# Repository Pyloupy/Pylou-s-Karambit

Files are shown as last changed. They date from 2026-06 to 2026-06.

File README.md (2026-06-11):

# Pylou-s-Karambit








Hey there ! This is the GitHub Repo where I'll show my creation based of the Reaver Karambit from Valorant (cf photo down below) that I wanted to bring to life!

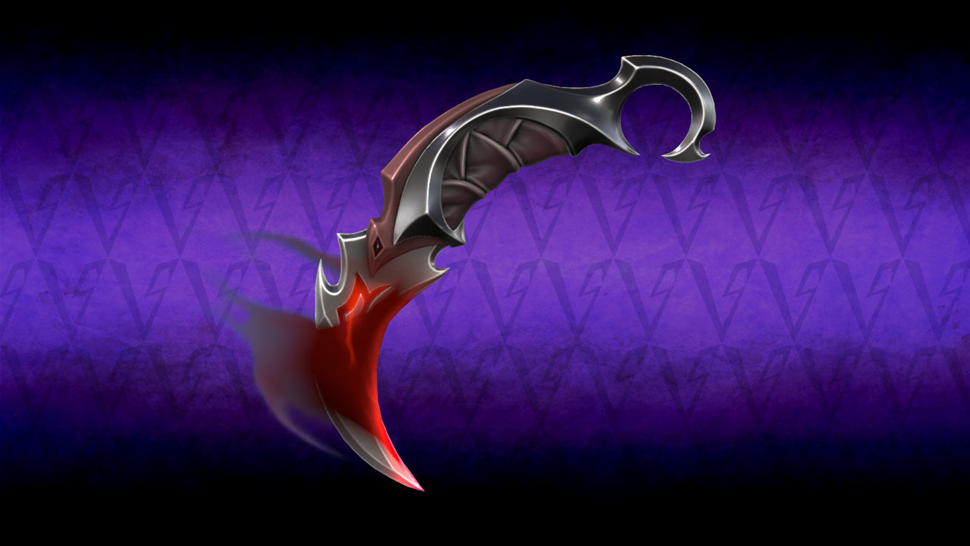
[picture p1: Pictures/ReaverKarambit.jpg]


I tried to make it as realistic as possible with LEDs A smoke generator and even movement and voice recognition!  You should see everything here that will make you able to recreate my work, GL :)
# Why ?
Well, you should first know that my work is completly useless and is purely aesthetic. It'll be able to cut butter at his peak or maybe set my house in fire if I did my job wrong ;-;

I wanted to make it as a fan of the game Valorant. A lot of recreation has been made because it is a very popular weapon skin in the game, but none tried to push the reality to the maximum, thats why I'm here !

At first, I created a prototype with not a lot of brain work behind it and it didnt work at all (as you can see in the photo) and I didn't even know why, so I gave up.

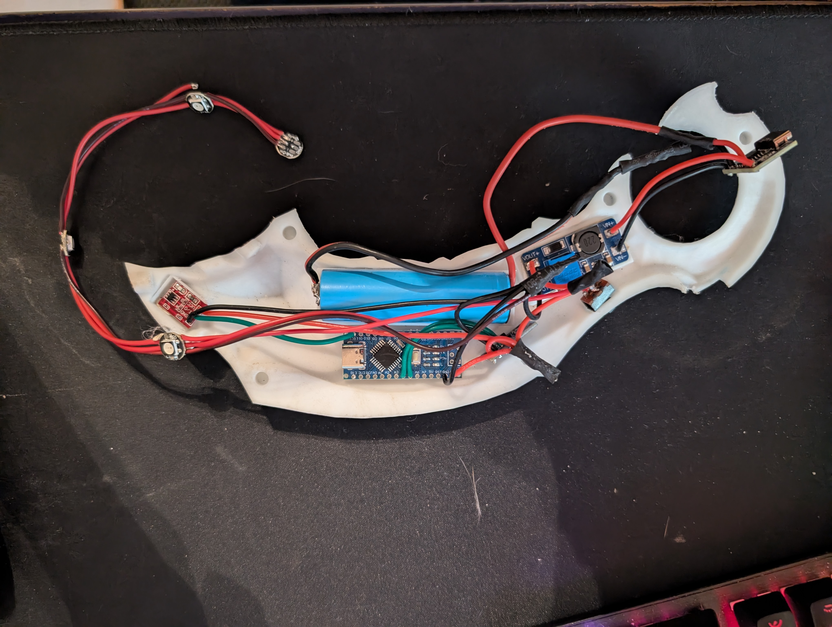
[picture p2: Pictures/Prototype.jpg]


My friends made a little fun of me and that's why when I hear of the Fallout project I decided to take my revenge and make a clean work that will work! That's enough story telling, let's get in the details !
# Functionalities
Here's an exhaustive list of the functionnalities I implemented into my Karambit that maybe I'll extend later when completing the build!
- A rechargeable Smoke generator based on a E-cig
- RGB Show! With the help of an SK6812MINI and an acrylic tube to make special effects!
- Movement detection : A list of pre-trained movement to make different effects base on which movement you execute! 
- Edge AI Speech recogntion : A list of pre-trained word-orders to activate/desactivate certain functionalities using a custom-trained TinyML model via the PDM microphone
- Magnetic sensor : to detect if it is on his stand (more and that down below)
- Ultra-Low Power Management : Hardware-level Deep Sleep (SYSTEM OFF) implementation with QSPI flash memory shutdown and Wake-on-Motion via I2C intterupts, to save battery life.
- Hardware Fail-Safe: Native Watchdog Timer (WDT) implementation directly addressing the ARM Cortex-M4 to prevent software failure / thermal runaway

I really wanted to make this as complete as possible while keeping it the size of a real karambit that can fit in you hands, it was quite a challenge.
# Zine page
But an image is worth thousands of words! I made the CAD of my model in blender because the karambit is a really complex shape and I'm a lot more comfortable with blender even thought it's not really made for this job and I had to deal with some issues due to blender. 

But I made a little render with an exploded view effect and I think it turned out well:

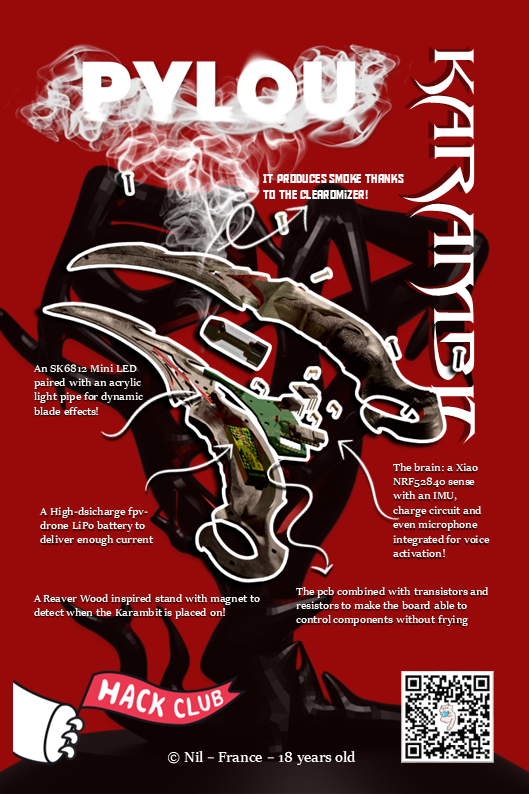
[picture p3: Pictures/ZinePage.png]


The design is around the exploded view where you can see every components linked to the explanation of his role. I think it's a cool way to show off everything you have to fit in this tiny space to make it work!
For the text name, I tried to make an effect with the smoke comming out of the resistor, although I think the idea is great, I'm not completly happy with the effect it gives. But overall I'm happy with my zine page!  
If you want, In the CAD folder you can find the "render.blend" file where I worked on the exploded view if you want to play with it :)

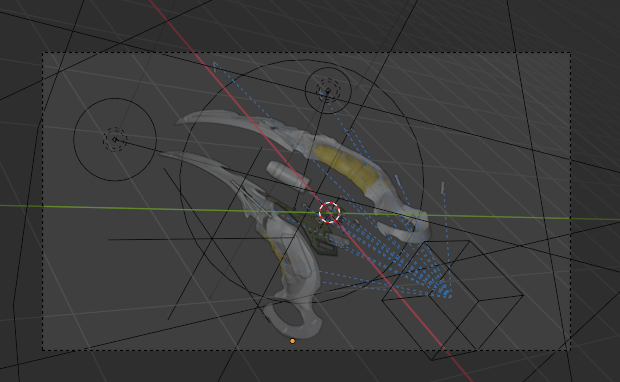
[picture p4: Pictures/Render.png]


# CAD
### the Karambit
Talking about CAD, as I said I did almost everything in Blender to work around the complex shape that the karambit is:

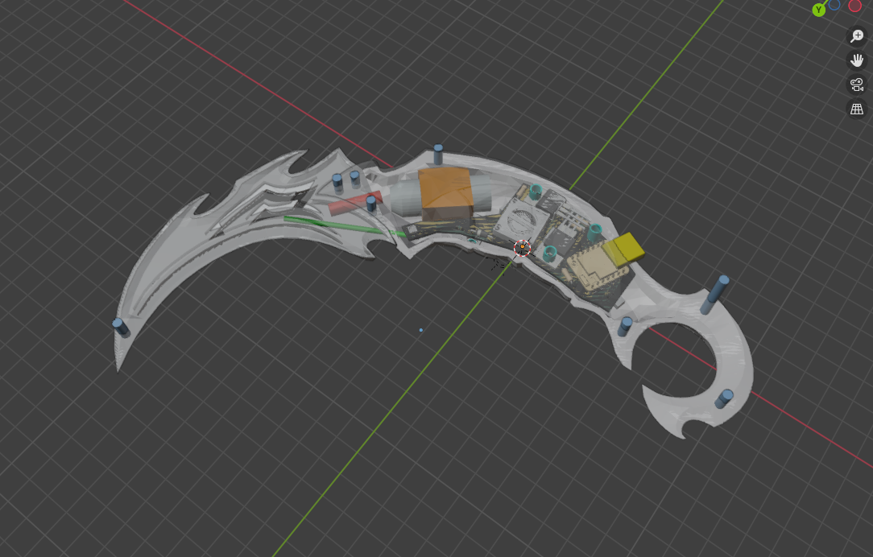
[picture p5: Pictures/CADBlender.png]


But I did use SOLIDWORKS when I had to model i couldn't find on the internet or to make a special adapter and then imported it in Blender.   
I think it is really more easy to work with it for placing components the way you want, and since I had so little space to work with it was perfect for me.  
I had to think about a way to:
- insert the pcb inside the handle
- fit the resistor inside the handle close the blade side and a good way to fix it
- make each part (2 handle part, 2 blade side) fit together with screw for a strong grip since you have to spin the karambit
- make a way to conduct light to the blade with no LEDs inside of it because the pcb couldn't go into the blade
- place usb-c port, reed sensor and cork hole for the tank in a way that is comfortable and make sense with the way it is held in the stand
Everything have his place and it's really not made randomely, I, in fact, made the pcb in the same time as the CAD files to rearange everything as I wanted to for optimal placement
### Stand
In the first place I wanted only to build the Karambit, but when I worked on the firmware, I realised that the board I selected didn't have a way to wake up itself throught the IMU.  
That's why I wanted a backup option for the wakeup system and I thought about a magnetic option with a stand. The idea is that when the karambit detects a magnet placed in the stand, It goes to sleep to save the battery, and when take it off it wakes up with special effects!

I wanted a dark and stylized way to show off the reaver karambit. With a bit of research I found this picture reference of the reaver woods from the game wayfinder that i didnt't even know existed:

<image src=./Pictures/ReaverWoods.png width=400>
  
I thought it completly matched the theme and made a model based on this reference image. It holds the knife with different branches and goes around like a protection.

<image src=./Pictures/Stand.png width=600>
  
I made it really big and I will have to print it in 5 different parts and glue it together, I really hope it will be strong enough to hold everything, but it should do the job.
### Adapters 

I also made some adapter in SOLIDWORKS to:
- Fix the resistor inside the handle
- Fix the pvc tube to the resistor
- Convert the airflow from the fan to the inside holes of the resistor

Thats is pretty much all for the CAD design

# PCB
Now for the PCB part! I did everything in Kicad which is a free software you can find [here](https://www.kicad.org/download/)
### Schematic
Overall, the schematic and electrical design is not really complicated as it consist only of the xiao nrf52840, pins for the battery, pins for the resistor, pins for the fan, 2 IRLZ44N mosfets and a couples of resistors and diode for protection.  
Here's the schematic:

<image src=./Pictures/Schematics.png width=800>
  
As you can see the mosfets control both the fan and resistor as the current could kill the microcontroller if connected directly to it.  
There are 10k pull-down resistors linked to the mosfets to prevent any unwanted turn on when the board is in deep sleep. The schottky 1N5819 diode is connected to the fan to prevent any back current that could fry the xiao board.

That is pretty much it, as I said nothing really complicated for the schematic, the hard part was to fit everything -->
### PCB design
Since the xiao boards include the charging system, IMU and microphone on itself, it really made the job easier.  
But the pcb itself is a bit small and in a strange shape since it had to fit in the curved form karambit.  
I think I couldn't really more include more components with the way I shaped the pcb, with the large trace I had to place for the current to flow easily into the heat resistor.
Here's how it looks:

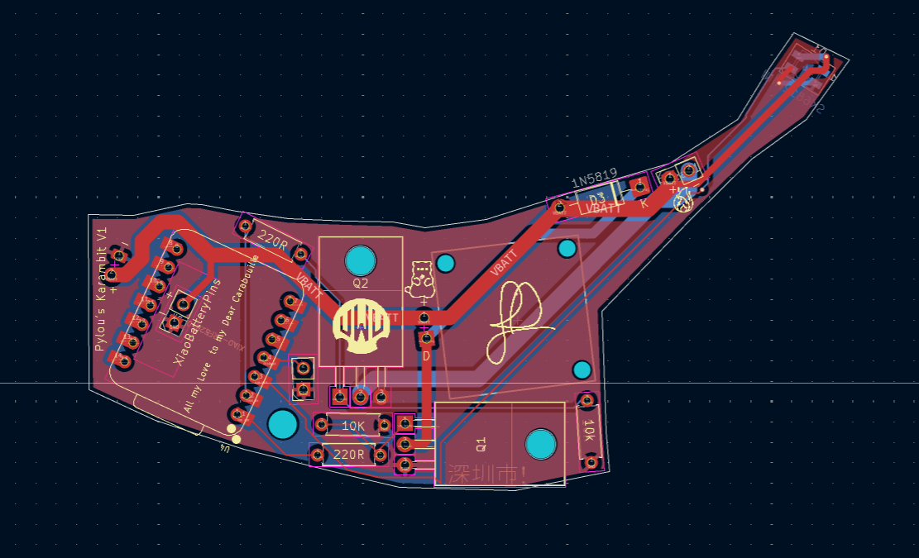
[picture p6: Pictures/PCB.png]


I also added holes to scew the pcb to the handle of the karambit, and I used the mosfets holes to fix the battery beneath the pcb.  
The SK6812MINI LEDs is place as far away as I could to place it near the blade of the karambit, that is why the pcb has this strange L shape.  
You could see that there is two times pins for the battery. The first one on the left side is to connect it to the BT2.0 connector that my battery use for a proper connection. The second one inside the xiao nrf52 footprint is placed this way because the pins for the battery module inside the xiao board is beneath it, so it will be easier for the solder job to place it this way instead of directly connect it to the BT2.0 connector.  

I have to mention I choosed to use the DIP version of the board and not the SMD one because I'm still a beginner with soldering electronics and it is way more easier to do it this way. But a way of impromevement could be to use the SMD version to not have two little wires hanging between the pcb and the microcontroller.

I think there is some details I could improve on the pcb but I didn't want to make it to complex for a V1 of this project as I really want to make it work like a charm !
# Firmware
## Installation
### Arduino
You will have to get the [Arduino IDE](https://support.arduino.cc/hc/en-us/articles/360019833020-Download-and-install-Arduino-IDE) to flash the xiao board. Then you will have to install the Seeed Xiao board inside the Arduino IDE (tutorial [here](https://wiki.seeedstudio.com/XIAO_BLE/#getting-started)) and make sure you select the mbed boards and not the classic one!  
After that you will have to install a couples of arduino libraries that I worked with, I made a folder called "Librairies" that you can copy-paste into your local Arduino folder in what I believe is ```/username/Documents/Arduino/librairies``` / install zip libraries or simply get your own with the library manager inside arduino. There is a txt file with links to all of them.

Then you'll just have to open the ReaverFirmware.ino file select the xiao nrf52840 board (mbed version) and flash the firmware, this can take a while with the speech recognition compilation.
### Custom Speech Recognition
I already trained a model with my voice, but I'm not sure it'll respond to yours. That's why I made a tool to make your own dataset and train your own speech recognition model! First you'll have to flash the ```AudioRecordPC.ino```file to the xiao board.   
Then there is a python script to record directly from the xiao nrf52 microphone! You will have to install [python](https://www.python.org/downloads/) and the keyboard librarie first with this simple command: ```py -m pip install keyboard``` .  
Then modify in the script the name of your folder you want to get the dataset in, and the name of the first order you are recording. Record you first word press "r" and repeat. The more you do the better, I'll say minimum of 100 of them. Then press "q" to quit and save every file. 

Now you just have to follow this [tutorial](https://wiki.seeedstudio.com/XIAO-BLE-PDM-EI/) with you own dataset. Here's the parameters that I personnaly used and that is working great for me: <image src=>
Don't forget to change in the Firmware code the import of the library to your own !  
⚠️ I recommend you record you files after build (see below) to have more realistic conditions
### Movement Recognition
For this, we again will use Edge Impulse AI, basically just follow the steps of [this](https://wiki.seeedstudio.com/XIAOEI/) tutorial and create your own movements you want to recognize.
It is basically the same thing as the voice recognition but here, you can easely record your samples via the website and nodejs, that will have to install (but everything is shown on the tutorial)

In the Firmware Tools folder you will find a script that makes you able to test your model. It is just adapted from an exemple of the movement recogntion library. It is basically the same thing but without installing additional library and using the official Seeed Xiao Nrf52 LSM6DS3 library.

Again the compilation can take a while, be patient.

It is very basic, and I will work on a continuous version to make it smooth and non-blocking. (This is also true for voice recogntion, but in this case the model also needs to be optimized)

(PS: implementation in the main code hasn't been made yet, it'll be when I'll start building)

If you don't want complex movement recognition you could just use this bit of code to detect any type of fast movements with acceleration:
```cpp
//in the void loop:
  currentMillis = millis();
  float gX = myIMU.readFloatAccelX();
  float gY = myIMU.readFloatAccelY();
  float gZ = myIMU.readFloatAccelZ();

  float magnitude = sqrt(gX * gX + gY * gY + gZ * gZ);
  /* Serial.println(gX);
  Serial.println(gY);
  Serial.println(gZ); */
  // Detect rapid movement
  if (magnitude > 2.5) {
    Serial.println("slash detected");
    fumee(); //Function for effetcs/smoke
    //delay(1000);
    startMillis = millis();//restart timer coz movement detected
  }else{
    fumeeOff(); //Function to disable effects/smoke
  }
```
(It's the code written in the main loop Firmware for now)
## How does it work ?
For this part, I really wanted to do an advanced job and use all the potential that the xiao nrf52840 as to offer.  
I choosed to use Arduino code for this project as it is efficient and well more documented than the other programming language options.  

There is a couple of files that is in the firmware folder, and I tried to comment everything on the way they work if you want to take a closer look!
Most of these folders are the firmware divided in multiples part to test every functionality of the firmware separetely:
- Testing the Deep Sleep mode and the different way to wake it up (IMU or reed sensor)
- Testing the Voice recognition model and the different way to use it (Continuous or no)
- Testing the watchdog (natively implemented inside the nrf52 chip from Nordic Semiconductor, this was a bit complicated to make it work) to prevent any errors crashing with the voice AI model
- Battery reading test
- IMU testing
- Fan/Led/mosfets testing
These scripts could help you when building the Karambit to check every components and maybe find what isn't working (if it's not working) especially with voice and movement recognition and maybe calibrate the battery reading, Deep Sleep and watchdog should work perfectly.

Have fun creating new effects/movement/orders to you karambit to make it personal!
#BOM
Now here's the BOM or aka how to get your components.  
There is link for everything mainly using Aliexpress. I personaly took the resistor with a French reseller so maybe you'll have to look somewhere else, (just search the model name).  
For paint, I took mine in a local store, be free to pick any colour you want to make your favorite variant of the reaver karambit!  
I ordered my pcb on Jlcpcb, it is great and cheap. For filament I used what I already had, but take whatever you want, it's best if it is strong and heat resistant.  
Careful for prices they may vary over time, Aliexpress is very volatile with there prices

Here's the BOM (you can also find it in CSV and xlsx format in the files):
| Item | Specs | Quantity | Buying Price(€) | Unit Price| Total Price (€) | Link | Tips |
| ---- | ----- | --- | --- | --- | --- | ---- | ---- |
| 18x14mm fan | 0.2 cfm, blow the smoke as it is in a closed case | 1 | 4.29 | 4.29 | 4.29 | [Link](https://fr.aliexpress.com/item/1005010476941631.html) | |
| 1N5819 Diode | Reverse polarity protection for the fan | 1 | 1.33 | 0.0248 | 0.0248 | [Link](https://fr.aliexpress.com/item/1005001552094086.html) | Others diodes will work, check the specs and measurement | 
| 100x2mm acrylic tube | Conduct the light into the blade | 1 | 1.8 | 0.171 | 0.171 | [Link](https://fr.aliexpress.com/item/1005005536829247.html) |  |
| M2xL2xOD3.2 insert | to fix the blade the the handle | 5 | 1.9 | 0.019 | 0.095 | [Link](https://fr.aliexpress.com/item/1005006472702418.html) | It'll be cheaper to just buy a kit of different type of inserts |
| M2xL4xOD3,2 insert | to fix the 2 parts of the knife together | 6 | 2.25 | 0.0225 | 0.135 | [Link](https://fr.aliexpress.com/item/1005006472702418.html) |  |
| M3xL5xOD4,2 insert | to fix the pcb via the transistors holes | 3 | 1.82 | 0.0364 | 0.1092 | [Link](https://fr.aliexpress.com/item/1005006472702418.html) |  |
| Battery BETAFPV LAVA II 1S 480mah | LiHv with 95C rating to ensure enough current | 1 | 15.29 | 3.54 | 3.54 | [Link](https://fr.aliexpress.com/item/1005010775720329.html) | Other batteries could work just be sure the C rating is high enough (hard to check on most Aliexpress battery where only fpv drones C rating are precised) |
| Reed switch NC  | Low voltage GPS-23 (act as a sensor to detect if it's in the stand) | 1 | 5.79 | 5.79 | 5.79 | [Link](https://fr.aliexpress.com/item/1005006926125113.html) |  |
| Seeed Studio Xiao nRF52840 Sense | 64 Mhz processor, IMU and microphone integrated | 1 | 18.19 | 18.19 | 18.19 | [Link](https://fr.aliexpress.com/item/1005006988944671.html) |  |
| BT 2.0 male cable | to cleanly connect the battery to the pcb | 1 | 3.59 | 1.945 | 1.945 | [Link](https://fr.aliexpress.com/item/1005009623841974.html) |  |
| SK6812MINI LED | 35 35 ARGB Led  | 1 | 10.89 | 0.1089 | 0.1089 | [Link](https://fr.aliexpress.com/item/1005004931260882.html) | You should modify the pcb and take SK6812MINI-E (the E is important) It's a lot more easier to solder, I already have those so i will use them (in pain) |
| GS Air Eleaf Clearomizer | 2.5 ml tank / 1,5 ohm coil (included) | 1 | 7.5 | 7.5 | 7.5 | [Link](https://www.oliquide.com/Clearomiseurs-Eleaf-Eleaf-GS-Air.) |  |
| Transistor IRLZ44N | 47A max, Vgs=2V, to control both fan and heat coil | 2 | 2.06 | 0.206 | 0.412 | [Link](https://fr.aliexpress.com/item/1005009876208141.html) | Should be overkill, I took them coz I already had them |
| 6mm diameter PVC Tube | 6mm exterior diameter 4mm interior diameter, to conduct the smoke to the blade | 1 | 2.09 | 2.09 | 2.09 | [Link](https://fr.aliexpress.com/item/1005006173546510.html) |  |
| M2 Screws | Screws different lengths kit | 1 | 5.09 | 5.09 | 5.09 | [Link](https://fr.aliexpress.com/item/1005007278965396.html) | Might have to cut them, make sure to put a bolt before to not break the thread |
| Magnet | 8mm diameter | 1 | 3.59 | 0.07 | 0.07 | [Link](https://fr.aliexpress.com/item/1005011969218794.html) |  |
| Anti-slip pads | for the stand | 7 | 1.8 | 0.018 | 0.12 | [Link](https://fr.aliexpress.com/item/1005008980666002.html) |  |
| 200/1K Ω resistors | for transistor signal and pull-down | 2 each |  |  |  | Take any kit of resistors on Aliexpress it'll be useful in the future |  |
| Hyper CF PLA Filament | For printing the handles, blades, stand and adaptaters | 1 | 34.99 | 34.99 | 34.99 | [Link](https://store.creality.com/fr/products/hyper-pla-cf-carbone-fibre-1-75mm-filament-dimpression-3d-1kg) | It's just what I will be using coz i have it in stock, but anything can do the job ABS will be better for heat coil |
| Fake Leather | Auto-adhesive layer | 1 | 4.99 | 4.99 | 4.99 | [Link](https://fr.aliexpress.com/item/1005008381916334.html) |  |
| Mettalic Paint | Shiny paint weeee | 1 | 5 | 5 | 5 | Bought from local store |  |
| Red Metallic Paint | Shiny paint weeee | 1 | 5 | 5 | 5 | Bought from local store |  |
| PCB | 1.6mm two layers | 1 | 3 | 0.6 | 0.6 | Got it from jlcpcb but use whats cheaper in your region (jlcpcb is a great choice tho) |  |
| Shipping Price |  | ~10-15€ |  |  |  |  |  |
| Total Price |  | 109.55€ | 128.88$ |  |  |  |  |
| Total Buying Price (Because you'll buying multiples at once) |  | 150.45€ | 177$  |  |  |  |  |

# Build time !
It's now time to make the Karambit! If you're confused any time, be free to check the blender file to understand where everything is placed! Everything is named and (more or less) organized, I hope you'll understand everything :)

### **Step 1:** Printing

First print everything from the STLs folder with your filament, it should be around 800g gram worth of filament, (I hope for you that everything fits in your printer, for reference mine is an ender 3 V3 KE).  

⚠️ Be careful when printing the stand, you will have to stop the print at a certain height to insert the magnet inside the branches and then resume print.
Then glue everything together for the stand, sand it and paint it if you think that is necessary. I recommend you to do it at least for the Karambit parts to make it cleaner!
Don't forget to place the anti-slip pads below the stand for a stable structure!
Place the fake leather into both handles, mines auto-adhesive if you take the one linked in the BOM

### **Step 2** soldering:

Beforehand be careful with the reed sensor, you will have to cut a platic part from it : 

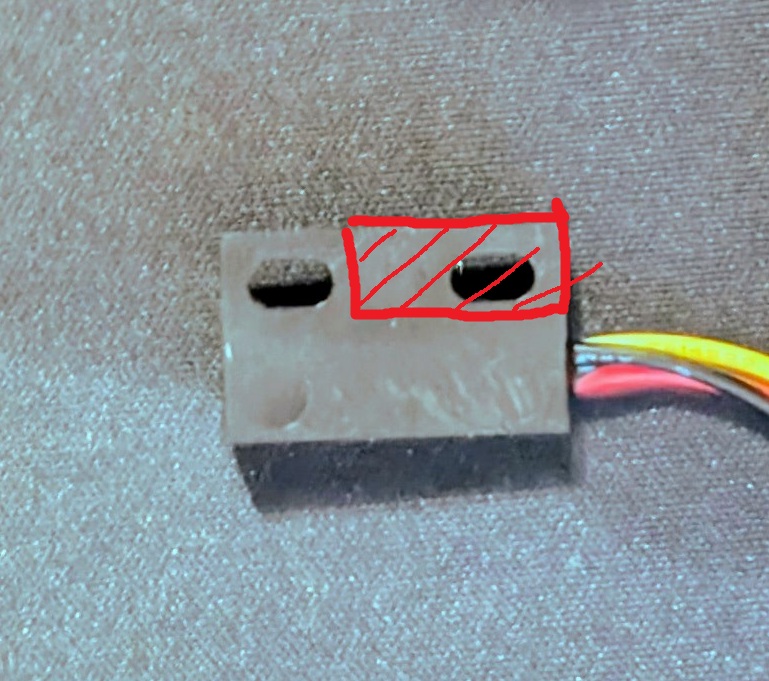
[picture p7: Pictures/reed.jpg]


without that it won't fit.  
Solder the xiao nrf52840 (dont forget connection for the battery), 200/1k ohms resistor, both mosfets, battery cable, fan, Schottky diode, SK6812MINI Led and Reed switch (let enough cable to play with) into the PCB and test everything with the different scripts in the Firmware folder.  

With a soldering Iron place the differents inserts in there places.  

Drill a 6mm hole into the Resistor's tank (check alignement with the hole made in the blade) and glue the tube to the tank with a waterproof glue like epoxy (will add a picture on that when i'll do it)
Solder + and - 18awg or less cable to the resistor as it shows on this image(then solder it to the PCB with enough length to play with):  (will add a picture on that when i'll do it)

### Step 3: assembling:
Fix the battery below the PCB with the adpater and screws/bolt.  
Fix the PCB into the handle with the scews.  
Fix the Resistor with the adapter printed and screws. (Careful for the orientation !) (PS: photo's comming when ill finish build)
Fix the Fan Adapter to the fan when screwing the fan.

Take the joint from the part you removed earlier from the clearomizer and place it on the adapter, then put it with the 6mm tube into the resistor. 

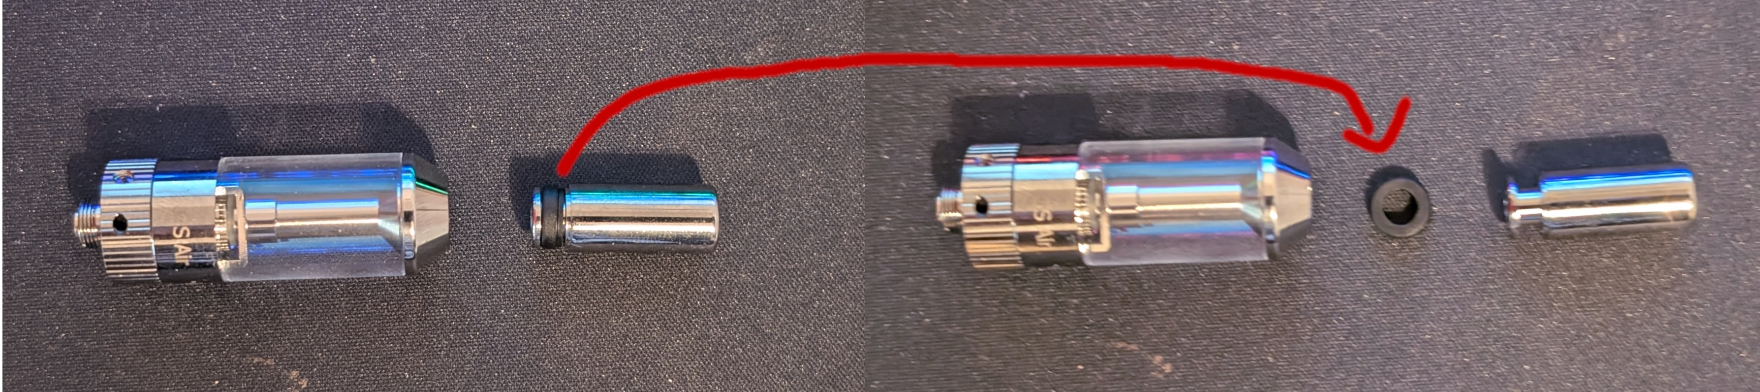
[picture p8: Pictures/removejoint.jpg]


Then block the left side of the base to force the airflow to go throught the coil : 

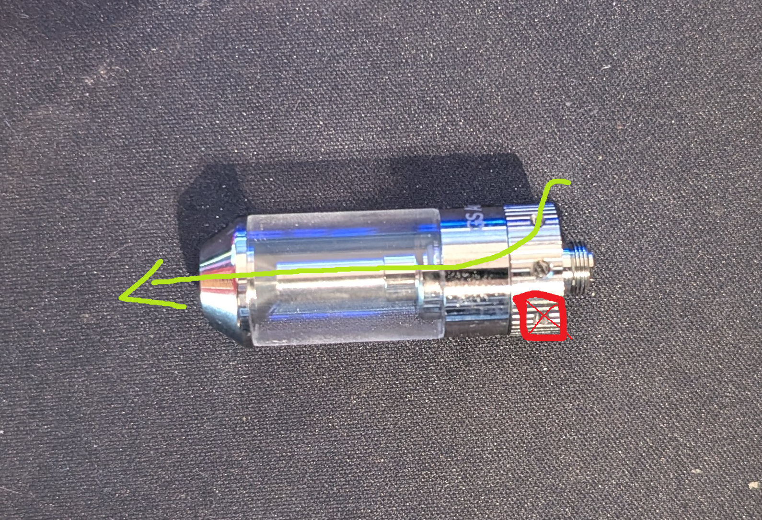
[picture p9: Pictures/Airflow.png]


Fix the first blade to the handle.

Cut and insert the acrylic tube into the handle and place it above the LED, if it doesn't transmit light good enough, try sanding the sides of the acrylic tube.  
Fix the reed switch to the handle.

Finally fix the other blade to the other handle and fix both handles together, upload the firmware when you are sure everything works and you're good to go!

# Special Thanks !

Thanks to my boy Carabouille for participating with me and qualify before me (bravo!)

Thanks to the Hack Club community for this incredible opurtinty that represent fallout!

Thanks to the UwU GanG to exist and be the best RL team imaginable :).

Thanks to Seeed Studio for the xiao boards (cyu in Shenzhen, plzzzzzz make more exemples code on your board ty)

Thanks to Emmanuel Macron for giving me so much money in scolarship, the goat
<br/>
<br/>
<br/>

See you in Shenzhen ;).

<br/>
<br/>
<br/>

\- Pylou

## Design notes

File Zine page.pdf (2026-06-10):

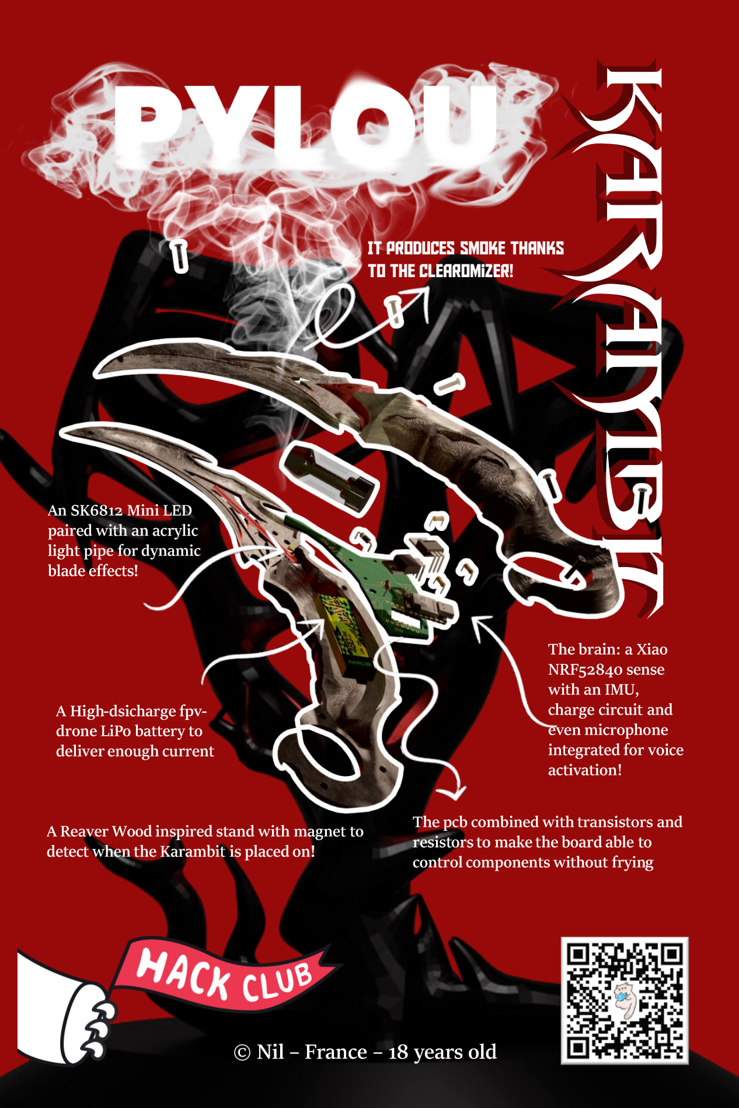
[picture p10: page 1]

# KARAMBIT

It ProduceS smoke thanks
to the clearomizer!

The brain: a Xiao
NRF52840 sense
with an IMU,
charge circuit and
even microphone
integrated for voice
activation!

An SK6812 Mini LED
paired with an acrylic
light pipe for dynamic
blade effects!

A High -dsicharge fpvdrone LiP o battery to
deliver enough current

The pcb combined with transistors and resistors to make the board able to control components without fryin g

## © Nil – France – 18 years old

A Reaver Woodinspired stand with magnet to detectwhen the Karambit is placed on!

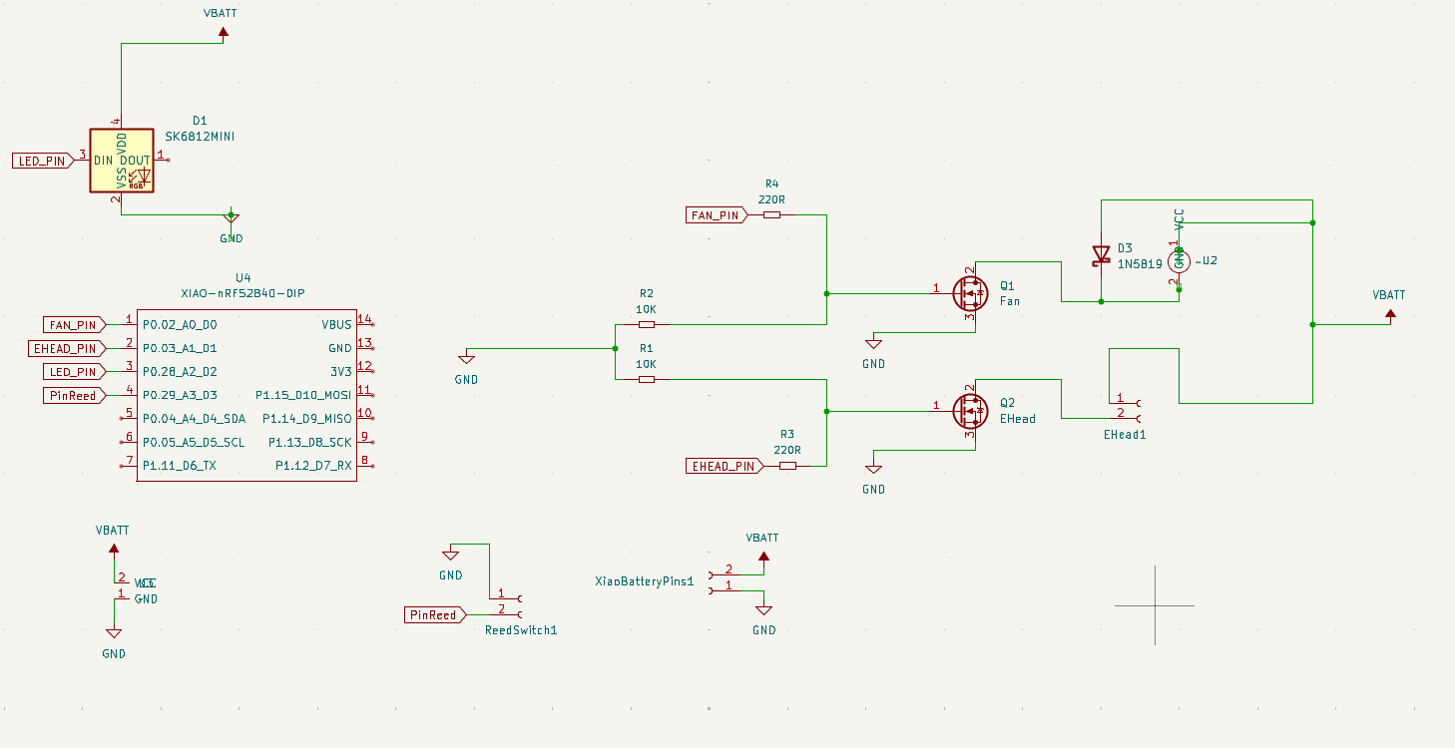
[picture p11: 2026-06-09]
Pictures/Schematics.png

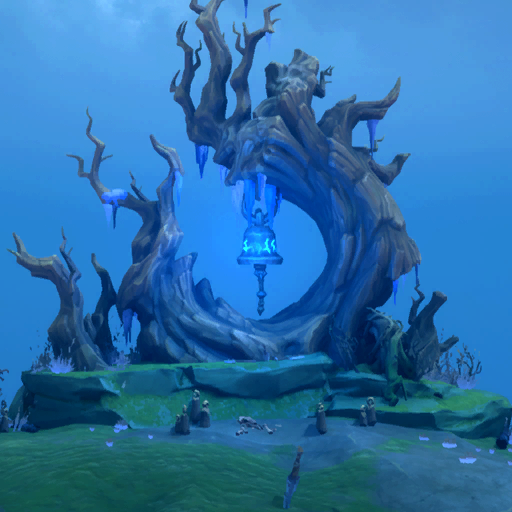
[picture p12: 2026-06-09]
Pictures/ReaverWoods.png

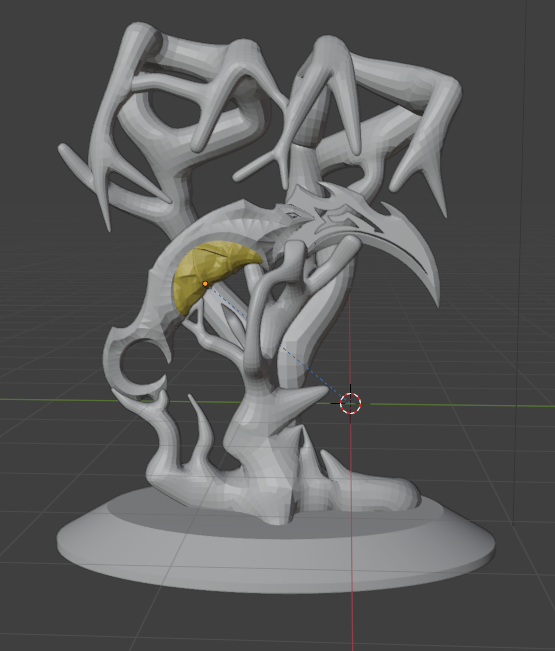
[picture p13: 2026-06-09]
Pictures/Stand.png

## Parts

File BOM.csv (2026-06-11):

Item | Specs | Quantity | Buying Price (€) | Unit Price (€) | Total Price (€) | Link | Tips
18x14mm fan | 0.2 cfm, blow the smoke as it is in a closed case | 1 | 4.29 | 4.29 | 4.29 | https://fr.aliexpress.com/item/1005010476941631.html
1N5819 Diode | Reverse polmarity protection for the fan | 1 | 1.33 | 0.0248 | 0.0248 | https://fr.aliexpress.com/item/1005001552094086.html | Others diodes will work, check the specs and measurement
100x2mm acrylic tube | Conduct the light into the blade | 1 | 1.8 | 0.171 | 0.171 | https://fr.aliexpress.com/item/1005005536829247.html | It'll be cheaper to just buy a kit of different type of inserts
M2xL2xOD3,2 insert | to fix the blade the the handle | 5 | 1.9 | 0.019 | 0.095 | https://fr.aliexpress.com/item/1005006472702418.html
M2xL4xOD3,2 insert | to fix the 2 parts of the knife together | 6 | 2.25 | 0.0225 | 0.135 | https://fr.aliexpress.com/item/1005006472702418.html
M3xL5xOD4,2 insert | to fix the pcb via the transistors holes | 3 | 1.82 | 0.0364 | 0.1092 | https://fr.aliexpress.com/item/1005006472702418.html
Battery BETAFPV LAVA II 1S 480mah | LiHv with 95C rating to ensure enough current | 1 | 15.29 | 3.5475 | 3.5475 | https://fr.aliexpress.com/item/1005010775720329.html | Others battery could work just be sure the C rating is higgh enough (hard to chekc on most Aliexpress battery where only fpv drones C rating are precised)
Reed switch NC | Low voltage GPS-23 (act as a sensor to detect if it's in the stand) | 1 | 5.79 | 5.79 | 5.79 | https://fr.aliexpress.com/item/1005006926125113.html
Seeed Studio Xiao nRF52840 Sense | 64 Mhz processor, IMU and microphone integrated | 1 | 18.19 | 18.19 | 18.19 | https://fr.aliexpress.com/item/1005006988944671.html
BT 2.0 male cable | to cleanly connect the battery to the pcb | 1 | 3.59 | 1.945 | 1.945 | https://fr.aliexpress.com/item/1005009623841974.html
SK6812MINI LED | 35 35 ARGB Led | 1 | 10.89 | 0.1089 | 0.1089 | https://fr.aliexpress.com/item/1005004931260882.html | You should modify the pcb and take SK6812MINI-E (the E is important) It's a lot more easier to solder, I already have those so i will use them (in pain)
GS Air Eleaf Clearomizer | 2.5 ml tank / 1,5 ohm resistance (included) | 1 | 7.5 | 7.5 | 7.5 | https://www.oliquide.com/Clearomiseurs-Eleaf-Eleaf-GS-Air.
Transistor IRLZ44N | 47A max, Vgs=2V, to control both fan and heart resistance | 2 | 2.06 | 0.206 | 0.412 | https://fr.aliexpress.com/item/1005009876208141.html | Could be overkill I took them coz I already had them
6mm diameter PVC Tube | 6mm exterior diameter 4mm interior diameter, to conduct the smoke to the blade | 1 | 2.09 | 2.09 | 2.09 | https://fr.aliexpress.com/item/1005006173546510.html
M2 Screws | Screws different lengths kit | 1 | 5.09 | 5.09 | 5.09 | https://fr.aliexpress.com/item/1005007278965396.html | Might have to cut them, make sure to put a bolt before to not break the filtrage
Magnet |  | 1 | 3.59 | 0.0718 | 0.0718 | https://fr.aliexpress.com/item/1005011969218794.html
200/1K Ω resistors | for transistor signal and pull-down | 2 each |  |  |  | Take any kit of resistors on Aliexpress it'll be useful in the future
Hyper CF PLA Filament | For printing the handles, blades, stand and adaptaters | 1 | 34.99 | 34.99 | 34.99 | https://store.creality.com/fr/products/hyper-pla-cf-carbone-fibre-1-75mm-filament-dimpression-3d-1kg | It's just what I will be using coz i have it in stock, but anything can do the job ABS will be better for heat resistance
Fake Leather | Auto-adhesive layer | 1 | 4.99 | 4.99 | 4.99 | https://fr.aliexpress.com/item/1005008381916334.html
Mettalic Paint | Shiny paint weeee | 1 | 5 | 5 | 5 | Bought from local store
Red Metallic Paint | Shiny paint weeee | 1 | 5 | 5 | 5 | Bought from local store
PCB | 1.6mm two layers | 1 | 3 | 0.6 | 0.6 | Got him from jlcpcb but use whats cheaper in your region (jlcpcb is a great choice tho)
Shipping Price |  | ~10-15€
Total Price (€) |  | 109.55
Total Price ($) |  | 128.88
Total Buying Price (Because you'll buying multiples at once) € |  | 150.45
Total Buying Price (Because you'll buying multiples at once) $ |  | 177

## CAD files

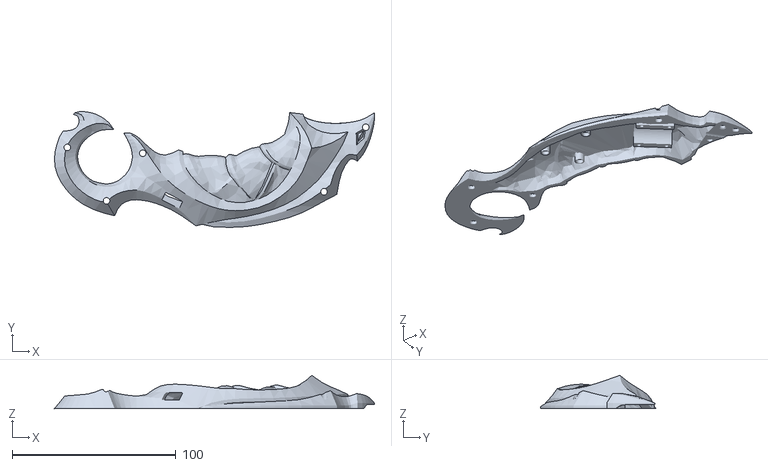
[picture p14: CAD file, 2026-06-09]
STLs/Main Reav.stl
195.7 x 70.8 x 20.4

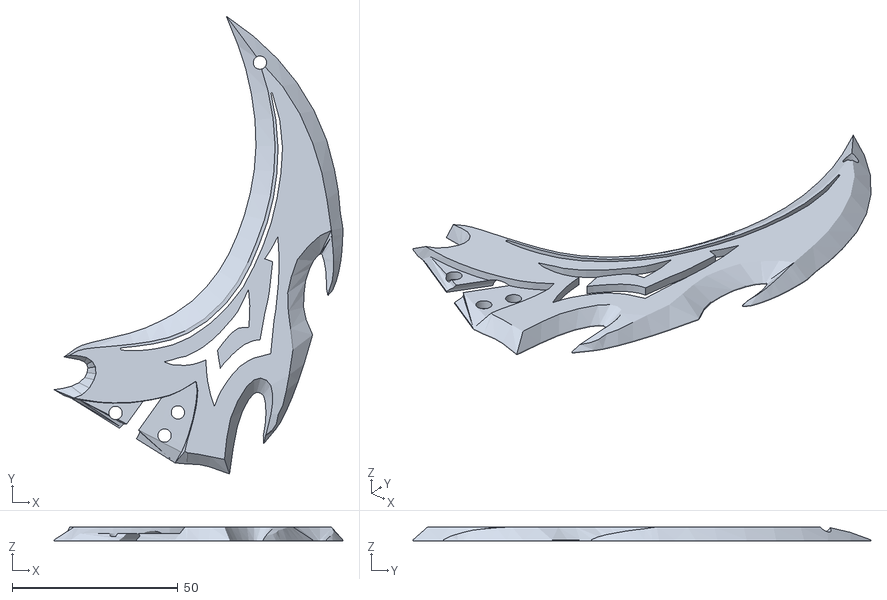
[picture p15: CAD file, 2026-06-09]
STLs/Blade Main.stl
87.1 x 138.1 x 4.24

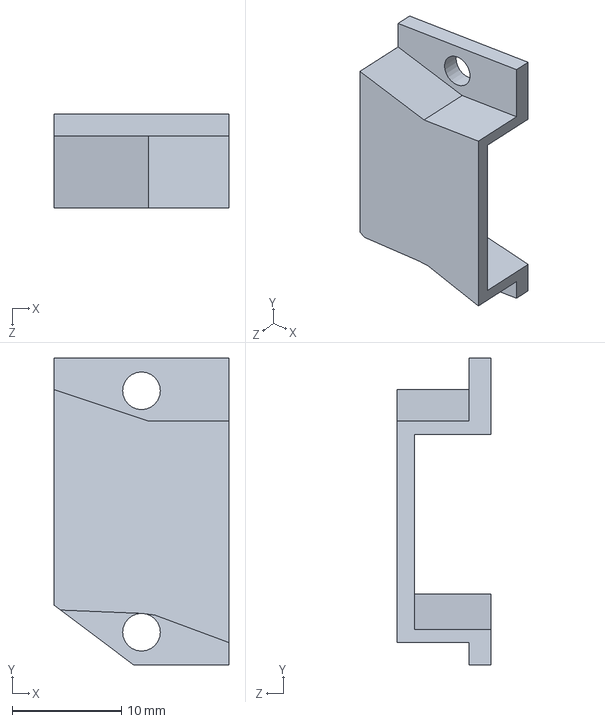
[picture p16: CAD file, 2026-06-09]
CAD - Blender/Battery support.SLDPRT
16.0 x 28.1 x 8.60 mm

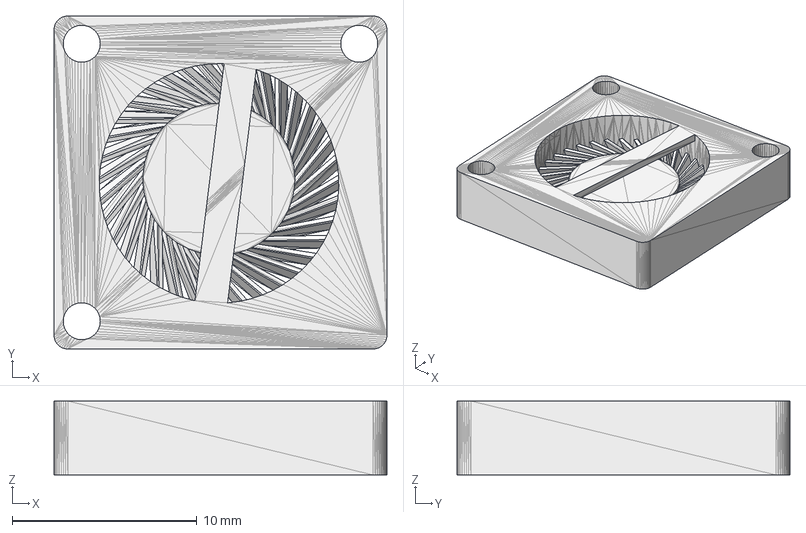
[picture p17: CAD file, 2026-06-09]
PCB/fan.step
18.0 x 18.0 x 4.00 mm

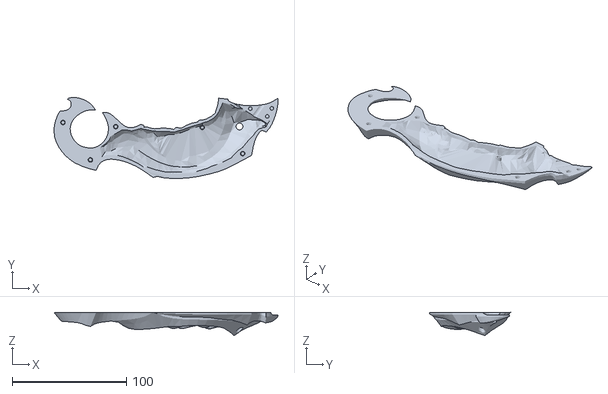
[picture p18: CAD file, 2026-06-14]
STLs/Side Reav.stl
195.7 x 70.8 x 20.4

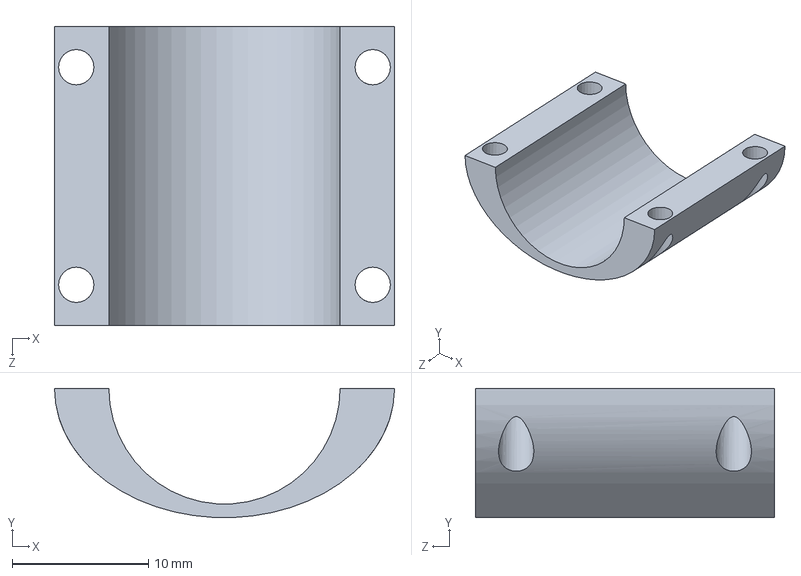
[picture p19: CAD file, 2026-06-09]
CAD - Blender/Resistor support.SLDPRT
25.0 x 9.49 x 22.0 mm

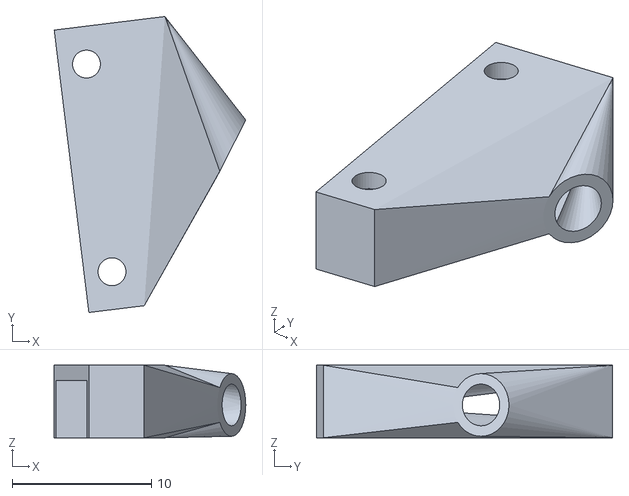
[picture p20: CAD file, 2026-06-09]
STLs/FanAdapter.stl
13.7 x 21.2 x 5.20

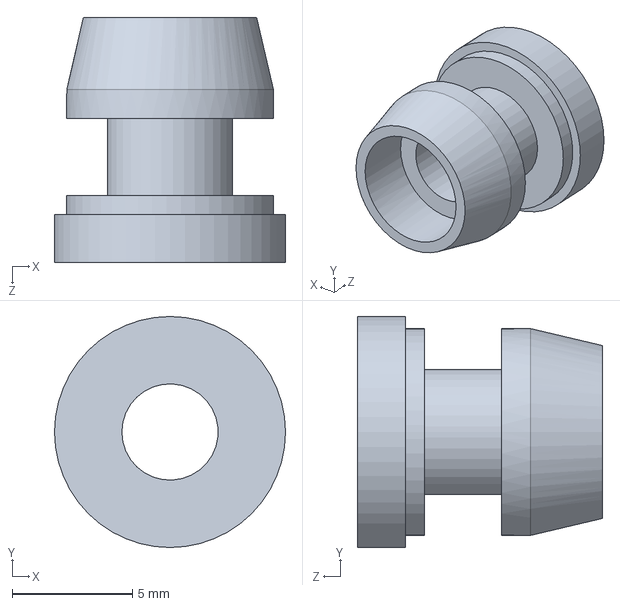
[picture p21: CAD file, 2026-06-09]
CAD - Blender/Adapter-Coil-Tube.SLDPRT
9.60 x 9.60 x 10.2 mm

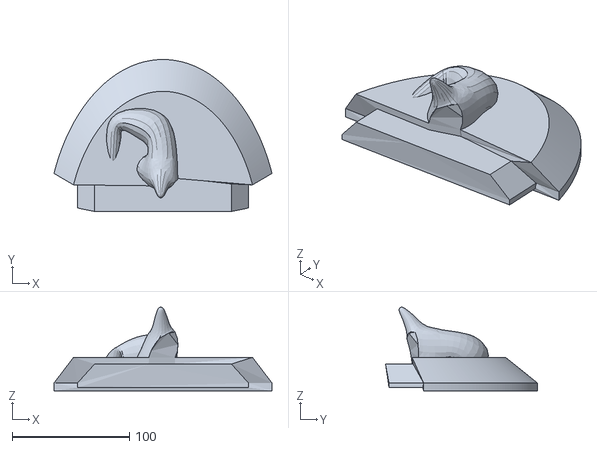
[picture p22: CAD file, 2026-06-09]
STLs/Stand Left Side.stl
185.6 x 129.4 x 71.2

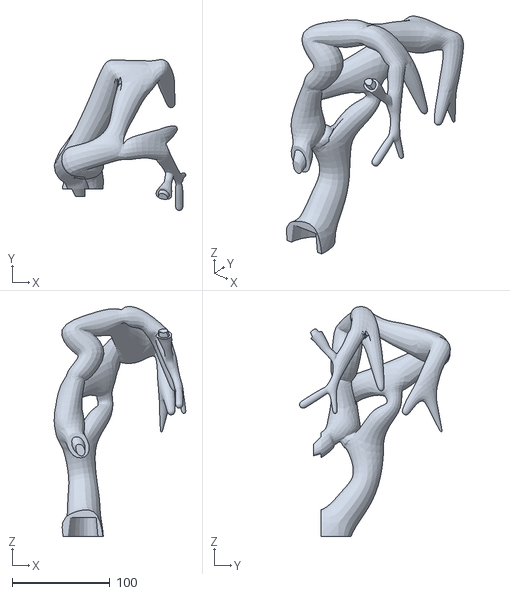
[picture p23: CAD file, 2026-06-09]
STLs/Tree Right Side.stl
134.8 x 154.6 x 235.5

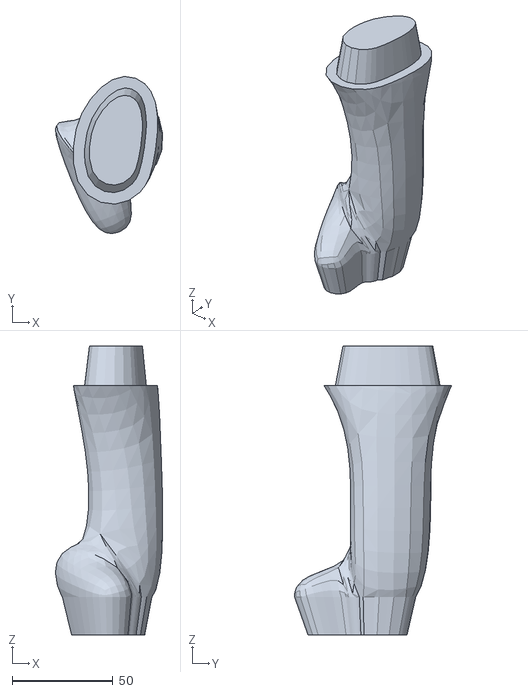
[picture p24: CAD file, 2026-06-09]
STLs/Tree Bottom.stl
53.3 x 78.1 x 143.6

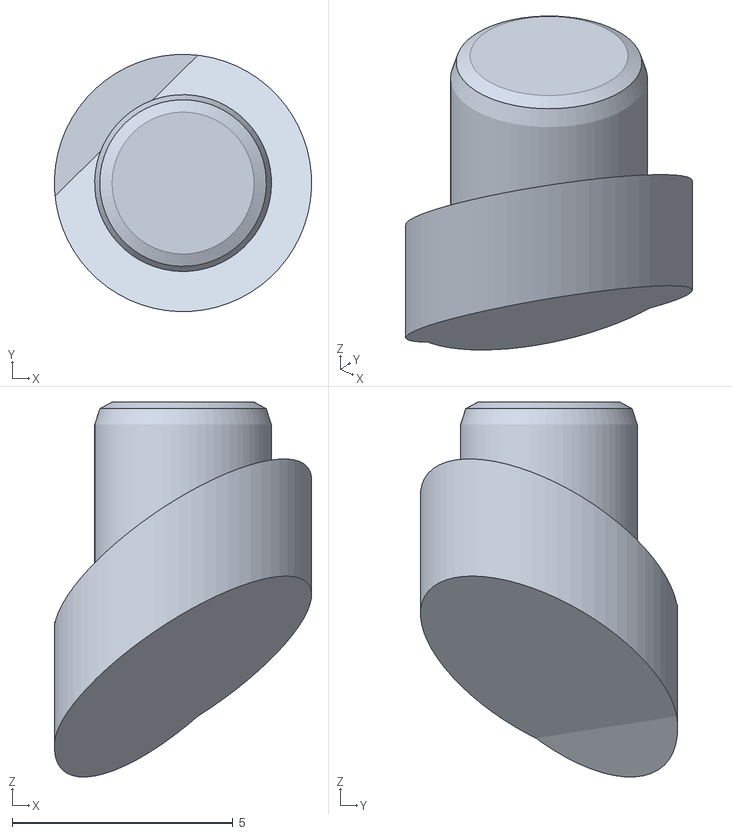
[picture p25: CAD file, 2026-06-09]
STLs/TubeCork.stl
5.82 x 5.82 x 8.48

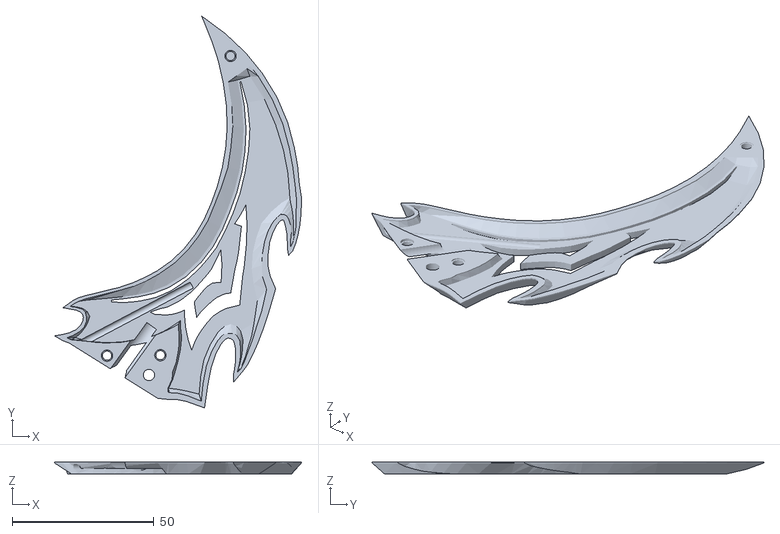
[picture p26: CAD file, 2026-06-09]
STLs/BladeSide.stl
87.1 x 138.1 x 4.24

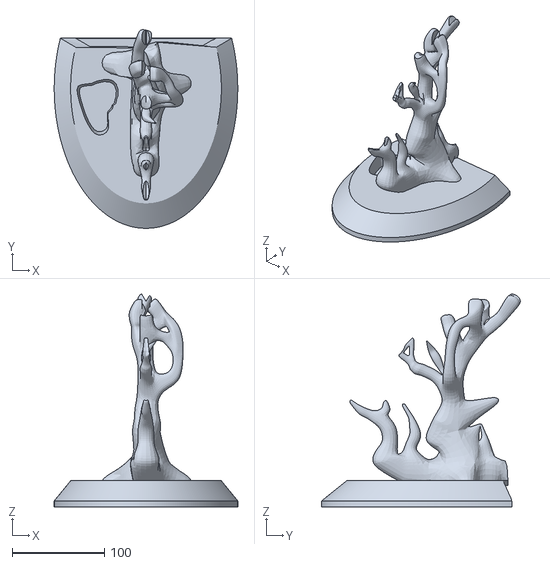
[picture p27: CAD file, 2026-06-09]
STLs/Stand Right Side.stl
199.0 x 215.4 x 230.9

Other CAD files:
STLs/Adapter-Coil-Tube.STL
STLs/Resistor support.STL
STLs/Battery support.STL
STLs/Tree Left Side.stl

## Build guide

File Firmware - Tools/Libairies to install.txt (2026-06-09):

adafruit neopixel: https://github.com/adafruit/adafruit_neopixel
IMU library: https://github.com/Seeed-Studio/Seeed_Arduino_LSM6DS3
don't forget to locally install the Speech recognition librarie!

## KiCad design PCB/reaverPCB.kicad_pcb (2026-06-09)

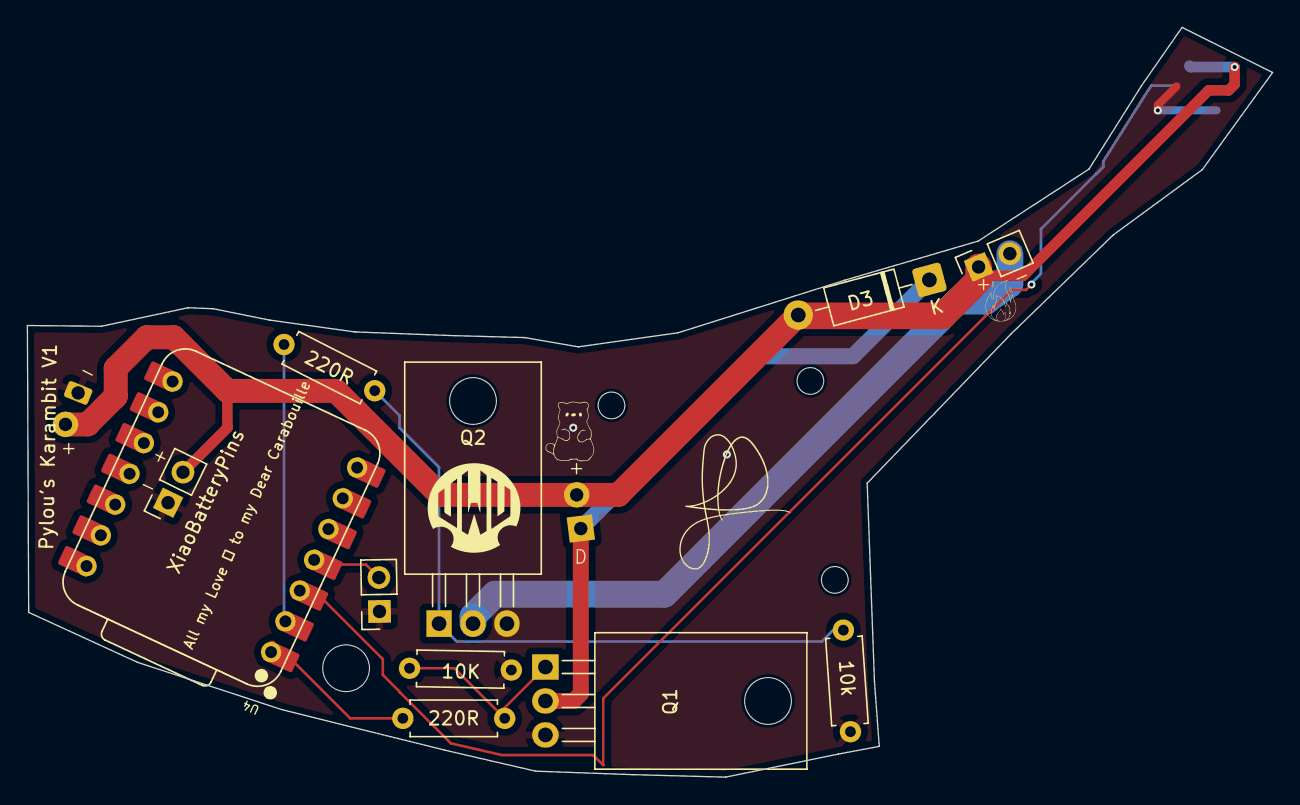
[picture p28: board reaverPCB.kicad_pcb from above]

Board: 2 copper layers, 93.2 x 56.1 mm, 14 parts (1 on the bottom side), 10 nets.

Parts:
10k: 10K; R_Axial_DIN0207_L6.3mm_D2.5mm_P7.62mm_Horizontal
D1: SK6812MINI; LED_SK6812MINI_PLCC4_3.5x3.5mm_P1.75mm
D3: 1N5819; D_DO-41_SOD81_P10.16mm_Horizontal
EHead1: Conn_01x02_Socket; PinSocket_1x02_P2.54mm_Vertical
Q1: Fan; TO-220-3_Horizontal_TabDown
Q2: EHead; TO-220-3_Horizontal_TabDown
R2: 10K; R_Axial_DIN0207_L6.3mm_D2.5mm_P7.62mm_Horizontal
R3, R4: 220R; R_Axial_DIN0207_L6.3mm_D2.5mm_P7.62mm_Horizontal
ReedSwitch1: Conn_01x02_Socket; PinSocket_1x02_P2.54mm_Vertical
U2: Fan18184
U3: 480mah
U4: XIAO-nRF52840-DIP
XiaoBatteryPins: Conn_01x02_Socket; PinSocket_1x02_P2.54mm_Vertical

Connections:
EHEAD_PIN: R3.1, U4.2 (P0.03_A1_D1)
FAN_PIN: R4.1, U4.1 (P0.02_A0_D0)
GND: 10k.1, D1.2 (VSS), Q1.3 (S), Q2.3 (S), R2.1, ReedSwitch1.1, U3.1 (GND), XiaoBatteryPins.1
LED_PIN: D1.3 (DIN), U4.3 (P0.28_A2_D2)
unnamed: D3.1 (K), Q1.2 (D), U2.2 (GND)
unnamed: EHead1.2, Q2.2 (D)
unnamed: Q1.1 (G), R2.2, R4.2
unnamed: 10k.2, Q2.1 (G), R3.2
PinReed: ReedSwitch1.2, U4.4 (P0.29_A3_D3)
VBATT: D1.4 (VDD), D3.2 (A), EHead1.1, U2.1 (VCC), U3.2 (VCC), XiaoBatteryPins.2

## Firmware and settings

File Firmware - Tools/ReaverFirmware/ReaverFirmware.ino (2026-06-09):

#include "LSM6DS3.h"
#include "Wire.h"
#include "nrfx_qspi.h"
#include <Adafruit_NeoPixel.h>
#include <PDM.h>
#include <PylouVoiceRecognitionReaver_inferencing.h>

//Watchdog value to reload
#define WDT_RELOAD_VALUE 0x6E524635

//Pins definitions
#define FanPin D0
#define eHeadPin D1
#define LedPin D2
#define ReedPin D3

// If your target is limited in memory remove this macro to save 10K RAM
#define EIDSP_QUANTIZE_FILTERBANK   0

#define VBAT_READ     32
#define CHG           23
#define VBAT_ENABLE P0_14
float Batterylvl;

//initiate Led
Adafruit_NeoPixel RGBLed(1, LedPin, NEO_GRB + NEO_KHZ800);


//initiate IMU
LSM6DS3 myIMU(I2C_MODE, 0x6A);

unsigned long startMillis;
unsigned long currentMillis;

/** Audio buffers, pointers and selectors */
typedef struct {
    int16_t *buffer;
    uint8_t buf_ready;
    uint32_t buf_count;
    uint32_t n_samples;
} inference_t;

static inference_t inference;
static signed short sampleBuffer[2048];
static bool debug_nn = false; 

int VRC; //choose action on VoiceRecognition

float confidence = 0.8;

//Object and function to disable the flash Memory to save up some power
static nrfx_qspi_config_t QSPIConfig;
void turnOffFlashMemory(){
    QSPIConfig.pins = { // Setup for the SEEED XIAO BLE - nRF52840                                                     
   .sck_pin     = 21,                                
   .csn_pin     = 25,                                
   .io0_pin     = 20,                                
   .io1_pin     = 24,                                
   .io2_pin     = 22,                                
   .io3_pin     = 23,                                
  }; 

  QSPIConfig.irq_priority = (uint8_t)NRFX_QSPI_CONFIG_IRQ_PRIORITY; //priority 7 lowest because we just want to send a command 0xB9 to turn the qspi flash to deep sleep mode          
  QSPIConfig.prot_if = {                                                        
    // .readoc     = (nrf_qspi_readoc_t)NRFX_QSPI_CONFIG_READOC,
    .readoc     = (nrf_qspi_readoc_t)NRF_QSPI_READOC_READ4O,       
    // .writeoc    = (nrf_qspi_writeoc_t)NRFX_QSPI_CONFIG_WRITEOC,     
    .writeoc    = (nrf_qspi_writeoc_t)NRF_QSPI_WRITEOC_PP4O,
    .addrmode   = (nrf_qspi_addrmode_t)NRFX_QSPI_CONFIG_ADDRMODE,   
    .dpmconfig  = false,                                            
  };  
  // initialize the QSPI flash and check any errors
  uint32_t Error_Code;
  Error_Code = nrfx_qspi_init(&QSPIConfig, NULL, NULL);
  if (Error_Code != NRFX_SUCCESS) {
    Serial.print("(QSPI_Initialise) nrfx_qspi_init returned : ");
    Serial.println(Error_Code);
  } else {
    Serial.println("(QSPI_Initialise) nrfx_qspi_init successful");
  }
  //setting up the command 0xB9 
  nrf_qspi_cinstr_conf_t cmd_config = {
      .opcode = 0xB9,
      .length = NRF_QSPI_CINSTR_LEN_1B,
      .io2_level = true,
      .io3_level = true,
      .wipwait = false,
      .wren = false
  };
  //sending the command
  nrfx_qspi_cinstr_xfer(&cmd_config, NULL, NULL);

  delayMicroseconds(5); 
  //uninitilaize the QSPI flash to avoid any comsumption
  nrfx_qspi_uninit();
}


void IMUSleepConfig(){
  myIMU.writeRegister(LSM6DS3_ACC_GYRO_CTRL1_XL, 0x10); // accel 12.5 Hz, 2g
  myIMU.writeRegister(LSM6DS3_ACC_GYRO_TAP_CFG1, 0x80); // activate Interupt
  myIMU.writeRegister(LSM6DS3_ACC_GYRO_WAKE_UP_THS, 0x03); // threshold
  myIMU.writeRegister(LSM6DS3_ACC_GYRO_WAKE_UP_DUR, 0x03); // duration to check, here no delay
  myIMU.writeRegister(LSM6DS3_ACC_GYRO_MD1_CFG, 0x20); // Signal to INT1 (which is connected to the board)
}


void goToSleep(){
  Serial.println("Turning device donw (deep sleep SYSTEM OFF)");
  Serial.flush(); // waiting for Serial to finish sending the message to avoid any errors
  turnOffFlashMemory();
  IMUSleepConfig();// calling the config for intterupt

  microphone_inference_end(); //end PDM

  nrf_gpio_cfg_sense_input(digitalPinToPinName(PIN_LSM6DS3TR_C_INT1), NRF_GPIO_PIN_PULLDOWN, NRF_GPIO_PIN_SENSE_HIGH); //Setting INT1 as an intterupt, digitalPinToPinName is necessary to get the right pin coz nordic use differents values that arduino (TRUST ME I STUCKED ON THIS FOR)
  nrf_gpio_cfg_sense_input(digitalPinToPinName(ReedPin), NRF_GPIO_PIN_PULLUP, NRF_GPIO_PIN_SENSE_LOW); //Reed Interrupt for wake up



  delay(200); //delay to not wake instantly

  NRF_POWER->SYSTEMOFF = 1;

  while(1); // nothing while execute after this coz CPU is disconnected from power supply :).
}


void configWatchdog(){
  NRF_WDT->CONFIG = (WDT_CONFIG_HALT_Pause << WDT_CONFIG_HALT_Pos) |
                    (WDT_CONFIG_SLEEP_Run << WDT_CONFIG_SLEEP_Pos);

  NRF_WDT->CRV = 32768 * 3; // Fix reset at 3s

  NRF_WDT->RREN |= WDT_RREN_RR0_Msk; // Activate Canal 0

  NRF_WDT->TASKS_START = 1; // Start the Watchdog

}

void checkDog(){
  NRF_WDT->RR[0] = WDT_RELOAD_VALUE;
}

void setup() {
  // Enable DC-DC converter Mode
  NRF_POWER->DCDCEN = 1;            // Enable DC/DC converter for REG1 stage

    // initialise ADC wireing_analog_nRF52.c:73
  analogReference(AR_DEFAULT);      // default 0.6V*6=3.6V 　wireing_analog_nRF52.c:73
  analogReadResolution(12);         // wireing_analog_nRF52.c:39
  delay(1000);

  //pin to use High charge current (100mA instead of 50mA)
  pinMode(P0_13, OUTPUT);   //Charge Current setting pin
  pinMode(P0_14, OUTPUT);   //Enable Battery Voltage monitoring pin
  digitalWrite(P0_13, LOW); //Charge Current 100mA  

  pinMode(CHG, INPUT_PULLUP);       // sleep current increases significantly without pull-up  
  digitalWrite(CHG, LOW);

  pinMode(VBAT_ENABLE, OUTPUT);
  digitalWrite(VBAT_ENABLE, HIGH);   // vattery voltage read disable  

  //Initiate eHead and fan mosfets pins and Reed sensor
  pinMode(eHeadPin, OUTPUT);
  pinMode(FanPin, OUTPUT);
  pinMode(ReedPin, INPUT_PULLUP);

  //begin RGB and set to White for test
  RGBLed.begin();

  //Turn off in case
  fumeeOff();

  uint32_t ResetReason = NRF_POWER->RESETREAS; //check reason of reset from deepsleep
  NRF_POWER->RESETREAS = ResetReason; // Erase register after reading it to not block it in next restarts

  if(ResetReason & POWER_RESETREAS_DOG_Msk){
    Serial.println("Watchdog reset!");
  }else{
    Serial.println("Normal/deepsleep reset");
  }

  // summary of inferencing settings (from model_metadata.h)
  ei_printf("Inferencing settings:\n");
  ei_printf("\tInterval: %.2f ms.\n", (float)EI_CLASSIFIER_INTERVAL_MS);
  ei_printf("\tFrame size: %d\n", EI_CLASSIFIER_DSP_INPUT_FRAME_SIZE);
  ei_printf("\tSample length: %d ms.\n", EI_CLASSIFIER_RAW_SAMPLE_COUNT / 16);
  ei_printf("\tNo. of classes: %d\n", sizeof(ei_classifier_inferencing_categories) / sizeof(ei_classifier_inferencing_categories[0]));

  if (microphone_inference_start(EI_CLASSIFIER_RAW_SAMPLE_COUNT) == false) {
      ei_printf("ERR: Could not allocate audio buffer (size %d), this could be due to the window length of your model\r\n", EI_CLASSIFIER_RAW_SAMPLE_COUNT);
      return;
  }

  //config Serial for tests, useless for final version
  /* Serial.begin(9600);
  while (!Serial);
  Serial.println("Serial opened, waiting 5s in case of flash new firmware"); */

  // Security boot for stuck in deep sleep:
  delay(5000);

  //Call .begin() to configure the IMUs
  if (myIMU.begin() != 0) {
      Serial.println("Device error");
  } else {
      Serial.println("Device OK!");
  }
  configWatchdog(); // start watchdog
  startMillis = millis();
  //goToSleep();
}

int VoiceRecognition(){
  if (inference.buf_ready == 0) {
        return -1; 
  }
  signal_t signal;
  signal.total_length = EI_CLASSIFIER_RAW_SAMPLE_COUNT;
  signal.get_data = &microphone_audio_signal_get_data;
  ei_impulse_result_t result = { 0 };

  EI_IMPULSE_ERROR r = run_classifier_continuous(&signal, &result, debug_nn);
  if (r != EI_IMPULSE_OK) {
      ei_printf("ERR: Failed to run classifier (%d)\n", r);
      return -1;
  }

  // Analyse the predictions
  for (size_t ix = 0; ix < EI_CLASSIFIER_LABEL_COUNT; ix++) {
      if(result.classification[ix].value>confidence){
        //compare label to these names to return int since return string is a bit complicated
        /* if (strcmp(result.classification[ix].label, "reaver") == 0) return 0;
        else if (strcmp(result.classification[ix].label, "allumeToi") == 0) return 1;
        else if (strcmp(result.classification[ix].label, "fumee") == 0) return 2; */
        return ix; //noise = 2 allumetoi = 0 reaver = 3 fumee = 1
      } 
  }
  #if EI_CLASSIFIER_HAS_ANOMALY == 1
      ei_printf("    anomaly score: %.3f\n", result.anomaly);
  #endif

  inference.buf_ready = 0; //reset data from mic

  return -1;
}

static void pdm_data_ready_inference_callback(void)
{
    int bytesAvailable = PDM.available();

    // read into the sample buffer
    int bytesRead = PDM.read((char *)&sampleBuffer[0], bytesAvailable);

    if (inference.buf_ready == 0) {
        for(int i = 0; i < bytesRead>>1; i++) {
            inference.buffer[inference.buf_count++] = sampleBuffer[i];

            if(inference.buf_count >= inference.n_samples) {
                inference.buf_count = 0;
                inference.buf_ready = 1;
                break;
            }
        }
    }
}

static bool microphone_inference_start(uint32_t n_samples)
{
    inference.buffer = (int16_t *)malloc(n_samples * sizeof(int16_t));

    if(inference.buffer == NULL) {
        return false;
    }

    inference.buf_count  = 0;
    inference.n_samples  = n_samples;
    inference.buf_ready  = 0;

    // configure the data receive callback
    PDM.onReceive(&pdm_data_ready_inference_callback);

    PDM.setBufferSize(4096);

    // initialize PDM with:
    // - one channel (mono mode)
    // - a 16 kHz sample rate
    if (!PDM.begin(1, EI_CLASSIFIER_FREQUENCY)) {
        ei_printf("Failed to start PDM!");
        microphone_inference_end();

        return false;
    }

    // set the gain, defaults to 20
    PDM.setGain(127);

    return true;
}

/**
 * @brief      Wait on new data
 *
 * @return     True when finished
 */
static bool microphone_inference_record(void)
{
    inference.buf_ready = 0;
    inference.buf_count = 0;

    while(inference.buf_ready == 0) {
        delay(10);
    }

    return true;
}

/**
 * Get raw audio signal data
 */
static int microphone_audio_signal_get_data(size_t offset, size_t length, float *out_ptr)
{
    numpy::int16_to_float(&inference.buffer[offset], out_ptr, length);

    return 0;
}

/**
 * @brief      Stop PDM and release buffers
 */
static void microphone_inference_end(void)
{
    PDM.end();
    free(inference.buffer);
}

float ReadBattery(){
  digitalWrite(VBAT_ENABLE, LOW); // vattery voltage read enable
  delay(10);

  uint32_t rawSum = 0;
  for(int i = 0; i < 256; i++) {
    rawSum += analogRead(VBAT_READ);
  }

  digitalWrite(VBAT_ENABLE, HIGH);  // vattery voltage read disable 

  float averageRaw = (float)rawSum / 256.0;

  return (averageRaw * 3.6 * 2.961) / 4096.0;  
}

void showBatteryLevel(){
  Batterylvl = ReadBattery();
  if(Batterylvl>3.7){
    RGBLed.setPixelColor(0, RGBLed.Color(0, 255, 0)); //Green for high battery lvl
  }else if (Batterylvl>3.4) {
    RGBLed.setPixelColor(0, RGBLed.Color(255, 128, 0)); //Orange for medium battery lvl
  }else{
    RGBLed.setPixelColor(0, RGBLed.Color(255, 0, 0)); //Red for low battery lvl
  }
  RGBLed.show();
}

void fumee(){
  analogWrite(FanPin, 128); //control fan speed test will be needed
  digitalWrite(eHeadPin, 1); //Turn on eHead
  RGBLed.setPixelColor(0, RGBLed.Color(255, 192, 203)); //different color here pink
}

void fumeeOff(){
  digitalWrite(FanPin, 0); //Turn off Fan
  digitalWrite(eHeadPin, 0); //Turn off eHead
  RGBLed.setPixelColor(0, RGBLed.Color(255, 255, 255));
}

void loop() {
  checkDog(); //Reload watchdog so it wont restart if everythings working properly

  currentMillis = millis();
  float gX = myIMU.readFloatAccelX();
  float gY = myIMU.readFloatAccelY();
  float gZ = myIMU.readFloatAccelZ();

  float magnitude = sqrt(gX * gX + gY * gY + gZ * gZ);
  /* Serial.println(gX);
  Serial.println(gY);
  Serial.println(gZ); */
  // Detect rapid movement
  if (magnitude > 2.5) {
    Serial.println("slash detected");
    fumee();
    delay(1000);
    startMillis = millis();//restart timer coz movement detected
  }else{
    fumeeOff();
  }
  //voiceRecogntion system
  int VRC = VoiceRecognition();
  switch(VRC){ //noise = 2 allumetoi = 0 reaver = 3 fumee = 1
    case -1: break; //nothing recognised or error
    case 0: break;//do smthg
    case 1: break; //do smthg
    case 2: break; //noise, do nothing
    case 3: break; //do smthg
  }

  //Gotosleep if inactivity of detect on stand and show battery level before
  if (digitalRead(ReedPin) || currentMillis-startMillis>60000){
    showBatteryLevel();
    delay(1500);
    checkDog();
    delay(1500);
    goToSleep();
  }
  if(currentMillis - startMillis > 2000){
    Batterylvl = ReadBattery();
    if (Batterylvl<3.2){ //gotoSleep if battery lvl to low, blink in red to notice the user
      for(int i = 0; i<4; i++){
        RGBLed.setPixelColor(0, RGBLed.Color(255, 0, 0));
        RGBLed.show();
        delay(500);
        
        RGBLed.setPixelColor(0, RGBLed.Color(0, 0, 0));
        RGBLed.show();
        delay(500);
        checkDog();
      }
      goToSleep();
    }
  }
}

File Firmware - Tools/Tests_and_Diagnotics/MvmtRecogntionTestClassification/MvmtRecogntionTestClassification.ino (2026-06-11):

/* Includes ---------------------------------------------------------------- */
#include <Motion_Recogntion_with_XIAO_Nrf52_inferencing.h>
#include "LSM6DS3.h" // Library from seeed xiao, you can find it on the library folder, there's also a link in the library.txt file

LSM6DS3 IMU(I2C_MODE, 0x6A);


#define CONVERT_G_TO_MS2    9.80665f

//Constant when sampling is limited by 2G here it's not

//#define MAX_ACCEPTED_RANGE  2.0f

/* Private variables ------------------------------------------------------- */
static bool debug_nn = false; // Set this to true to see e.g. features generated from the raw signal

/**
* @brief      Arduino setup function
*/
void setup()
{
    // put your setup code here, to run once:
    Serial.begin(115200);
    // comment out the below line to cancel the wait for USB connection (needed for native USB)
    while (!Serial);
    Serial.println("Edge Impulse Inferencing Demo");

    if (!IMU.begin()) {
        ei_printf("Failed to initialize IMU!\r\n");
    }
    else {
        ei_printf("IMU initialized\r\n");
    }

    if (EI_CLASSIFIER_RAW_SAMPLES_PER_FRAME != 3) {
        ei_printf("ERR: EI_CLASSIFIER_RAW_SAMPLES_PER_FRAME should be equal to 3 (the 3 sensor axes)\n");
        return;
    }
}

/**
 * @brief Return the sign of the number
 * 
 * @param number 
 * @return int 1 if positive (or 0) -1 if negative
 */
float ei_get_sign(float number) {
    return (number >= 0.0) ? 1.0 : -1.0;
}

/**
* @brief      Get data and run inferencing
*
* @param[in]  debug  Get debug info if true
*/
void loop()
{
    ei_printf("\nStarting inferencing in 2 seconds...\n");

    delay(2000);

    ei_printf("Sampling...\n");

    // Allocate a buffer here for the values we'll read from the IMU
    float buffer[EI_CLASSIFIER_DSP_INPUT_FRAME_SIZE] = { 0 };

    for (size_t ix = 0; ix < EI_CLASSIFIER_DSP_INPUT_FRAME_SIZE; ix += 3) {
        // Determine the next tick (and then sleep later)
        uint64_t next_tick = micros() + (EI_CLASSIFIER_INTERVAL_MS * 1000);

        //IMU.readAcceleration(buffer[ix], buffer[ix + 1], buffer[ix + 2]); #### THIS WAS THE OLD CODE BUT THE XIAO LIBRARY DOESN'T HAVE THIS FUNCTION
        buffer[ix] = IMU.readFloatAccelX();
        buffer[ix+1] = IMU.readFloatAccelY();
        buffer[ix+2] = IMU.readFloatAccelZ();

        // Code for Sampling limitation, useless here
        /*for (int i = 0; i < 3; i++) {
            if (fabs(buffer[ix + i]) > MAX_ACCEPTED_RANGE) {
                buffer[ix + i] = ei_get_sign(buffer[ix + i]) * MAX_ACCEPTED_RANGE;
            }
        }*/ 

        buffer[ix + 0] *= CONVERT_G_TO_MS2;
        buffer[ix + 1] *= CONVERT_G_TO_MS2;
        buffer[ix + 2] *= CONVERT_G_TO_MS2;

        delayMicroseconds(next_tick - micros());
    }

    // Turn the raw buffer in a signal which we can the classify
    signal_t signal;
    int err = numpy::signal_from_buffer(buffer, EI_CLASSIFIER_DSP_INPUT_FRAME_SIZE, &signal);
    if (err != 0) {
        ei_printf("Failed to create signal from buffer (%d)\n", err);
        return;
    }

    // Run the classifier
    ei_impulse_result_t result = { 0 };

    err = run_classifier(&signal, &result, debug_nn);
    if (err != EI_IMPULSE_OK) {
        ei_printf("ERR: Failed to run classifier (%d)\n", err);
        return;
    }

    // print the predictions
    ei_printf("Predictions ");
    ei_printf("(DSP: %d ms., Classification: %d ms., Anomaly: %d ms.)",
        result.timing.dsp, result.timing.classification, result.timing.anomaly);
    ei_printf(": \n");
    for (size_t ix = 0; ix < EI_CLASSIFIER_LABEL_COUNT; ix++) {
        ei_printf("    %s: %.5f\n", result.classification[ix].label, result.classification[ix].value);
    }
#if EI_CLASSIFIER_HAS_ANOMALY == 1
    ei_printf("    anomaly score: %.3f\n", result.anomaly);
#endif
}
//Creates an error but it's working so IDK i just commented it out
#if !defined(EI_CLASSIFIER_SENSOR) || EI_CLASSIFIER_SENSOR != EI_CLASSIFIER_SENSOR_ACCELEROMETER
//#error "Invalid model for current sensor"
#endif

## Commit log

2026-06-09 Ajout de MainModel et Render
2026-06-11 Update BOM.csv with duplicate entries
    Added duplicate entries for Hyper CF PLA Filament and Fake Leather while removing Hyper CF PLA Filament and Fake Leather from the original list.
    [BOM.csv]
